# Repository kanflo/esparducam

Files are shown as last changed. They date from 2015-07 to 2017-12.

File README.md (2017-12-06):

# Esparducam
#### A low cost network camera for the ESP8266

This repository contains code and schematics to build a development board joining the ESP8266 with the [Arducam Mini](http://www.arducam.com/arducam-mini-released/) module. Build surveillance cameras, read your water meter, attach one to your kite.

<p align="center">
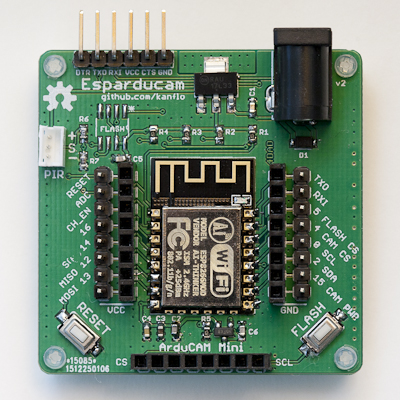
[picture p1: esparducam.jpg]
Esparducam board
  
</p>

The board design allows for small breakout boards to be attached. There currently is [a breakout board the the RFM69C](https://github.com/kanflo/esparducam/tree/master/hardware/ism-boardlet), [an ESP12 board with pogo pins](https://github.com/kanflo/esparducam/tree/master/hardware/esp-pinlet) and [one for swappable ESP12 modules](https://github.com/kanflo/esparducam/tree/master/hardware/esp-boardlet).

Oh, the accompanying blog posts are [here](http://johan.kanflo.com/building-a-low-cost-wifi-camera/), [here](http://johan.kanflo.com/a-versatile-esp8266-development-board/) and [here](http://johan.kanflo.com/esparducam-mini/).

### Usage

Clone the ESP Open RTOS repository. See the documentation for how to add your SSID name and password.

```
git clone --recursive https://github.com/Superhouse/esp-open-rtos.git
```

Add nedded extra modules to ESP Open RTOS ("EOR"):

```
cd esp-open-rtos/extras
git clone https://github.com/kanflo/eor-spi.git spi
git clone https://github.com/kanflo/eor-http-upload.git http-upload
```

Someday I'll start using the native EOR SPI driver, you have to bear with me for now :)

Set the environment variable ```$EOR_ROOT```to point to your EOR repository:

```
export EOR_ROOT=/path/to/esp-open-rtos
```

Clone this repository, make and flash:

```
git clone --recursive https://github.com/kanflo/esparducam.git
cd esparducam
make -j8 && make flash
```

The repository is preconfigured for the Esparducam board. Check ```config.h``` for building for the Esparducam Mini.

When flashing has completed, open a serial terminal to learn the IP number of your board. Open a web brower, point it to your IP and an image should be captured and displayed. While in the serial terminal, type ```help``` for a list of supported commands.

Start the python script ```server.py``` and type ```upload:<your IP>``` to capture, upload and display an image on your computer.

If you connect a [PIR module](http://www.ebay.com/sch/i.html?_trksid=PIR+module.TRS0&_nkw=PIR+module&_sacat=0) [eBay] to the JST connector of the Esparducam board you can use the command ```motion:on:<your ip>``` to have the board capture and upload an image when motion is detected. The Mini variant has a 3 pin slot for attaching a PIR but you need to check the pinout carefully. It should be VCC, OUT, GND but I have seen other combinations.

### Limitations

This is work in progress and there is currently very little error handling. Simultaneous clients will break the camera demo.

-

Licensed under the MIT license. Have fun!

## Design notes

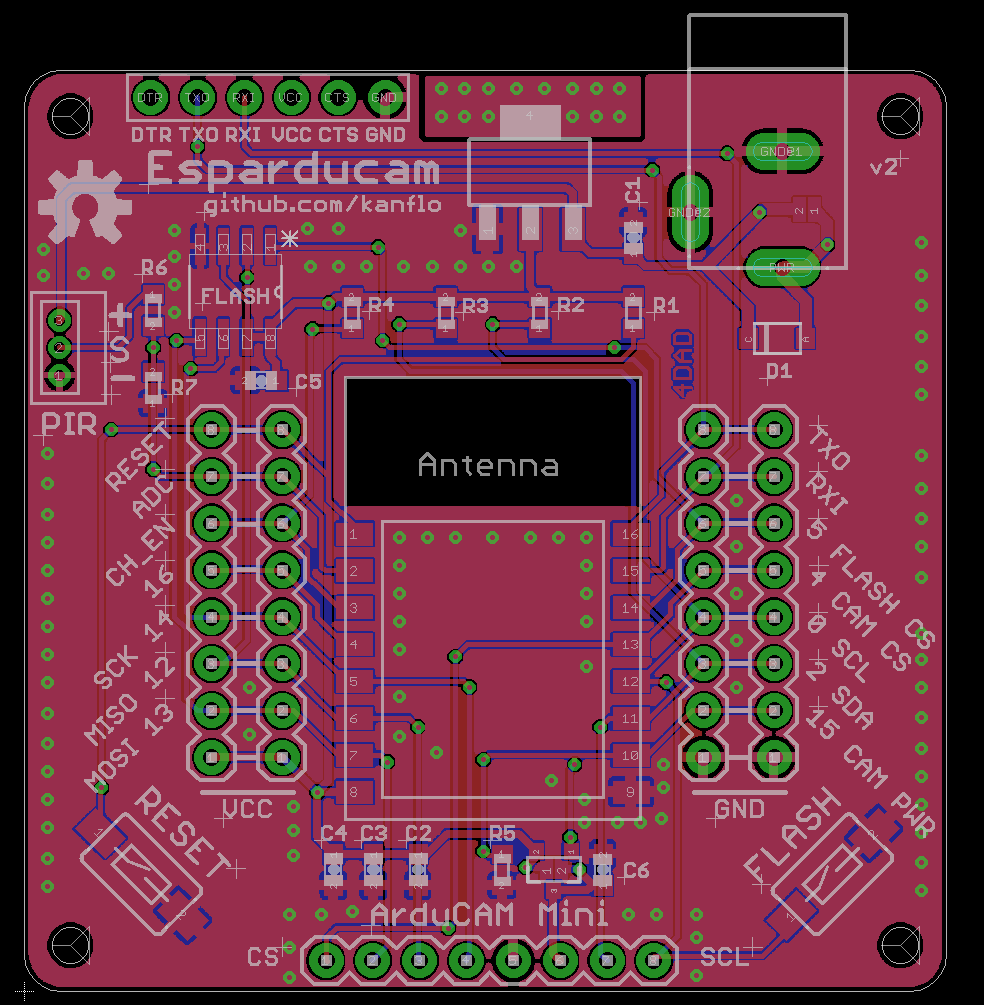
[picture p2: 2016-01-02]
hardware/esparducam-v2/esparducam-v2.png

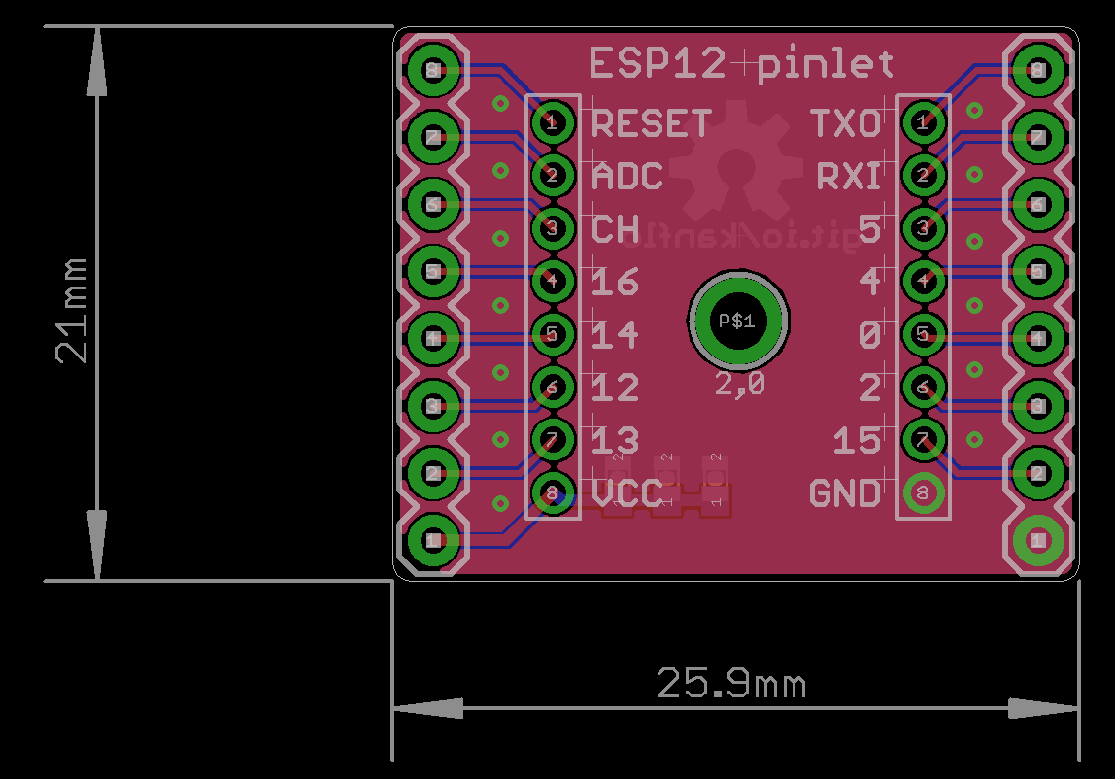
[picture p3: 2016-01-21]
hardware/esp-pinlet/esp-pinlet.png

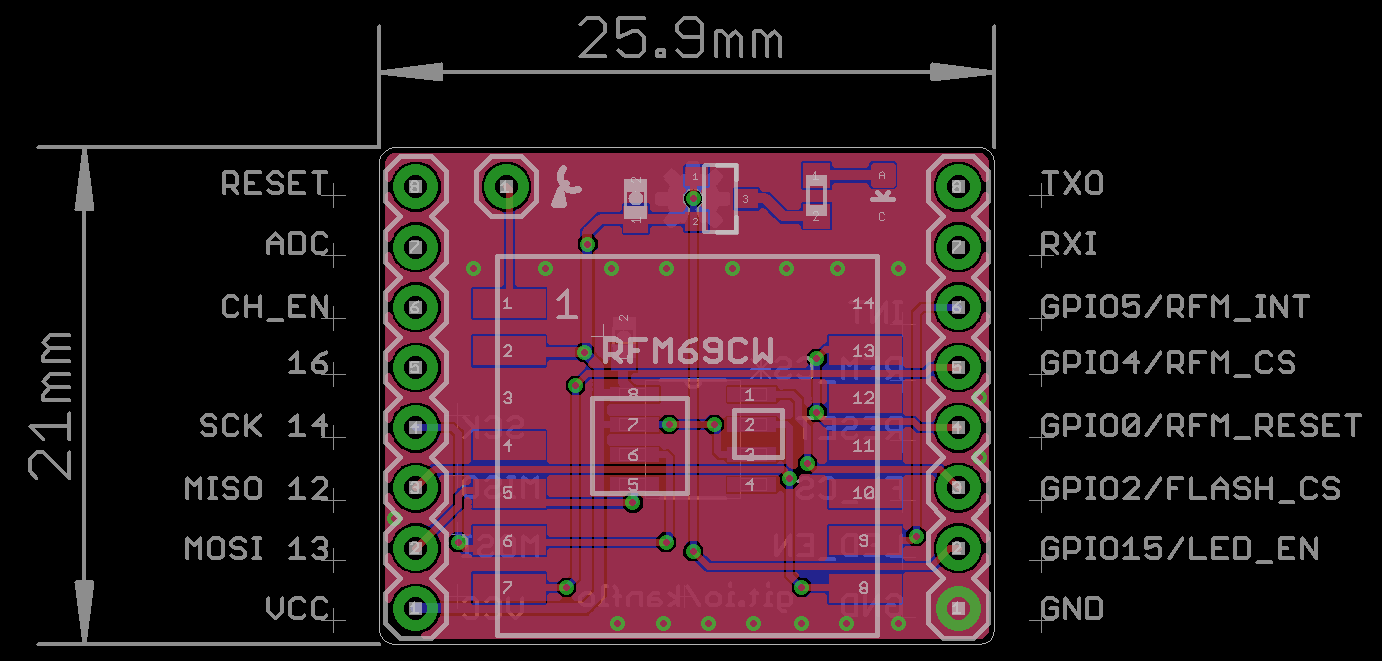
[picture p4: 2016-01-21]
hardware/ism-boardlet/ism-boardlet.png

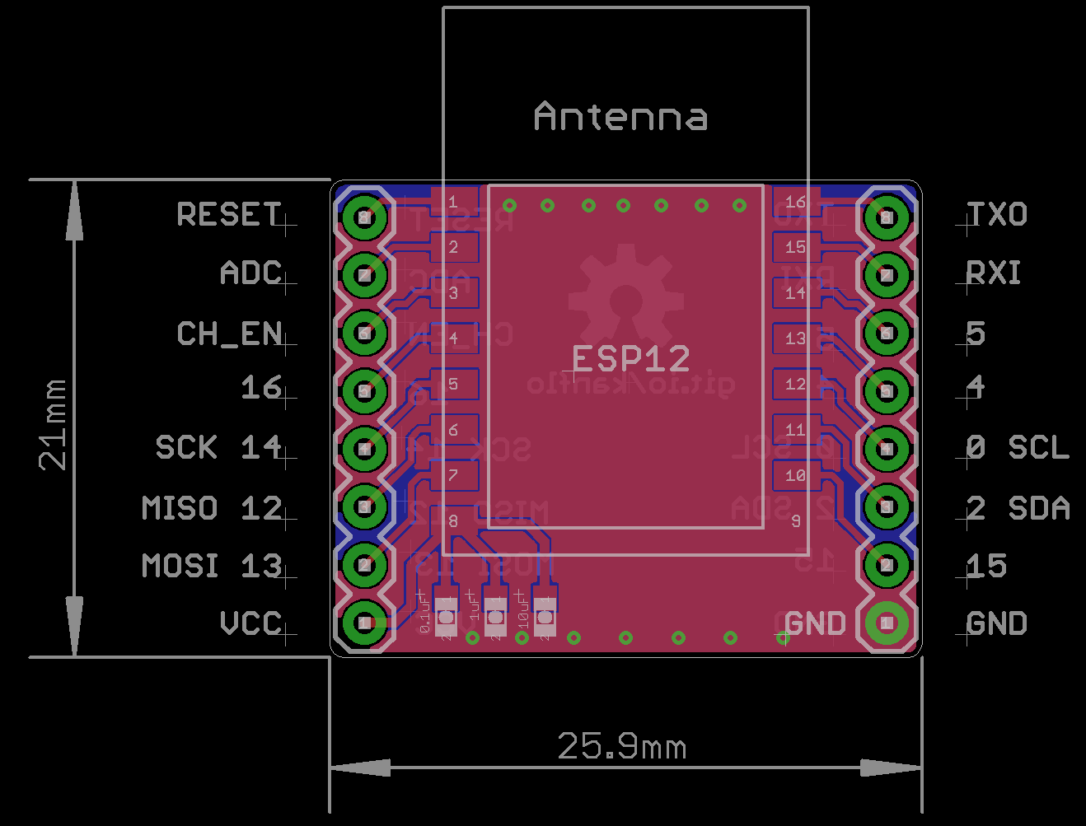
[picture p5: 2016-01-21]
hardware/esp-boardlet/esp-boardlet.png

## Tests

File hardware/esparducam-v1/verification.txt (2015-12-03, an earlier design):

Verification
------------
This document outlines the verification plan of the Esparducam v1 board.

No shorts found
 - checked VCC/GND
 - checked all ESP pins

Verification plan
 - Verify power - check
 - Barrel polarity - check
 - Regulator output (U1) - check
 - Verify mosfet power supply for ArduCAM module (Q1) - check
 - Produce a board with
    C1 C2
    R1 R2 R3 R4 R5 R6
    SPI flash
    Q1
    U1

Issues found
 - Footprint/silkscreen mismatch for the barrel connector.
 - Swapped RX/TX on the FTDI connector. Need to make a special cable, swap yellow and orange.
 - NCP1117 GND pin not directly routed to GND plane.
 - ArduCAM Mini has a pullup on its CS pin which is connected to GPIO15. The ESP will not boot with the ACAM module attached. Fix is to move CAM_CS to GPIO4.
 - One of the ESP modules had a broken Wifi antenna. Need a way to verify modules prior to mounting.
 - FTDI connector silk is ugly
 - Wrong footprint for Q1, selected SOT-323 instead of SOT-23. Luckily solder will make a '23 sit on the '323 pads :)

Planned changes for v2
 + Fix footprint of barrel connector.
 + Fix swapped UART RX/TX pins.
 + Fix FTDI connector silk.
 + Add label "Flash" under the SPI flash.
 + Replace BOOT label with FLASH.
 + Replace N-mosfet with a P-mosfet cutting power on the high side (check Harizanov's Funky with RFM12).
 + Move CAM_CS to GPIO 4.
 + Move CAM_PWR to GPIO 15.
 + NCP1117 GND pin not directly routed to GND plane.
 + Move SJ1 to the back side
 + Skip SJ2
 + Add protective diode with SJ bypass
 + Place 0.1uF, 1uF & 10uF close to ESP VCC
 + Add label for flash size under the board in the same manner as the "ESP type" label.
 + Change footprint for Q1 to SOT-23

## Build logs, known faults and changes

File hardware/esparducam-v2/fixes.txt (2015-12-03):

[X] Fix footprint of barrel connector.
[X] Fix swapped UART RX/TX pins.
[X] Move CAM_CS to GPIO 4.
[X] Move CAM_PWR to GPIO 15.
[X] Fix FTDI connector silk.
[X] Investigate a P-mosfet cutting power on the high side (check Harizanov's Funky with RFM12).
[X] NCP1117 GND pin not directly routed to GND plane.
[X] Skip SJ2.
[X] Investigate VCC filtering.
[X] Add label for flash size under the board in the same manner as the "ESP type" label.
[X] Add label "Flash" under the SPI flash.
[X] Replace BOOT label with FLASH.
[X] Check GPIO4 and GPIO5 (is the correct order TX, RX, GPIO5, GPIO4, ... ?)
[ ] Make the ESP12e pads 1mm wider
[X] Remove R6
[X] Check footprint of Q1 (seems to small)
[X] Add a schottky diode for reverse voltage protection and SJ bypass

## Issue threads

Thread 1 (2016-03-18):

Arduino friendly code

mkeyno, 2016-03-18:
hi @kanflo  and thanks for sharing the project , I'm arduino fan and I was wondering any plan to make your code in arduino  friendly environment such as arducam
BR

kanflo, 2016-03-18:
Thanks for taking interest @mkeyno. There already is a nice port for the Arduino environment at https://github.com/ArduCAM/Arduino (both AVR and ESP8266 based). I am afraid I will not find the time to make an Arduino version of my camera demo.

mkeyno, 2016-03-18:
thanks @kanflo for quick reply , yes I know those code and I was hopping to have your code in Arduino platform , thanks any way

Closed 2017-04-10.

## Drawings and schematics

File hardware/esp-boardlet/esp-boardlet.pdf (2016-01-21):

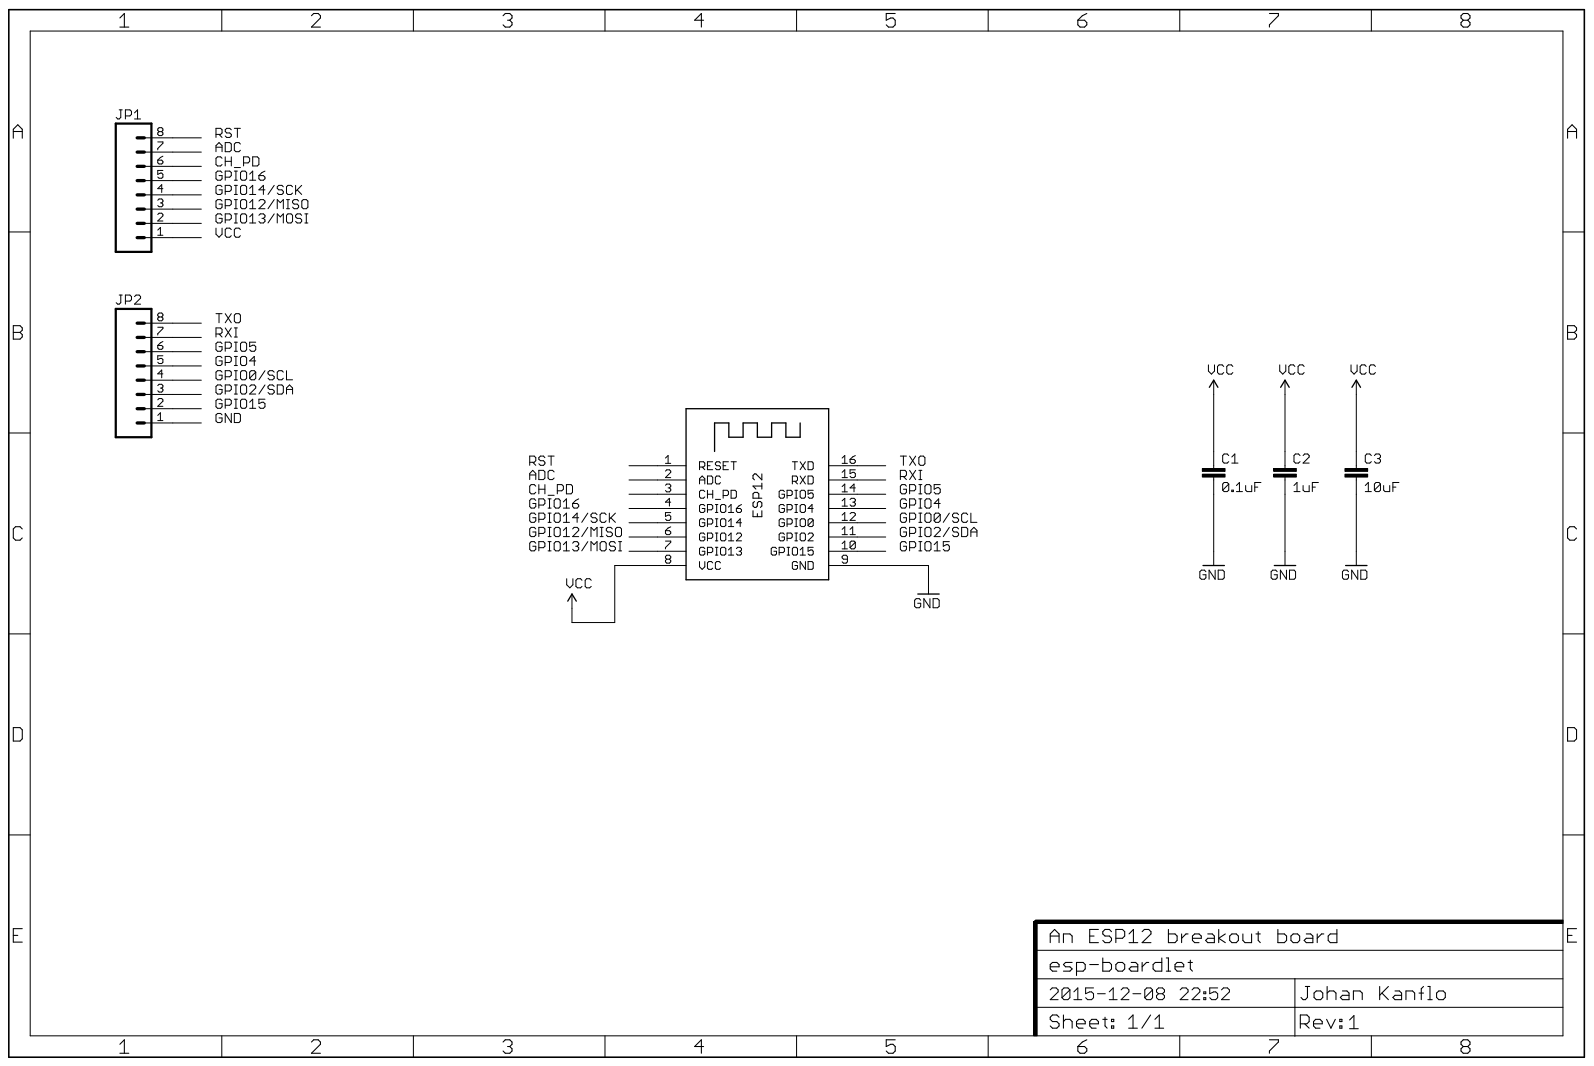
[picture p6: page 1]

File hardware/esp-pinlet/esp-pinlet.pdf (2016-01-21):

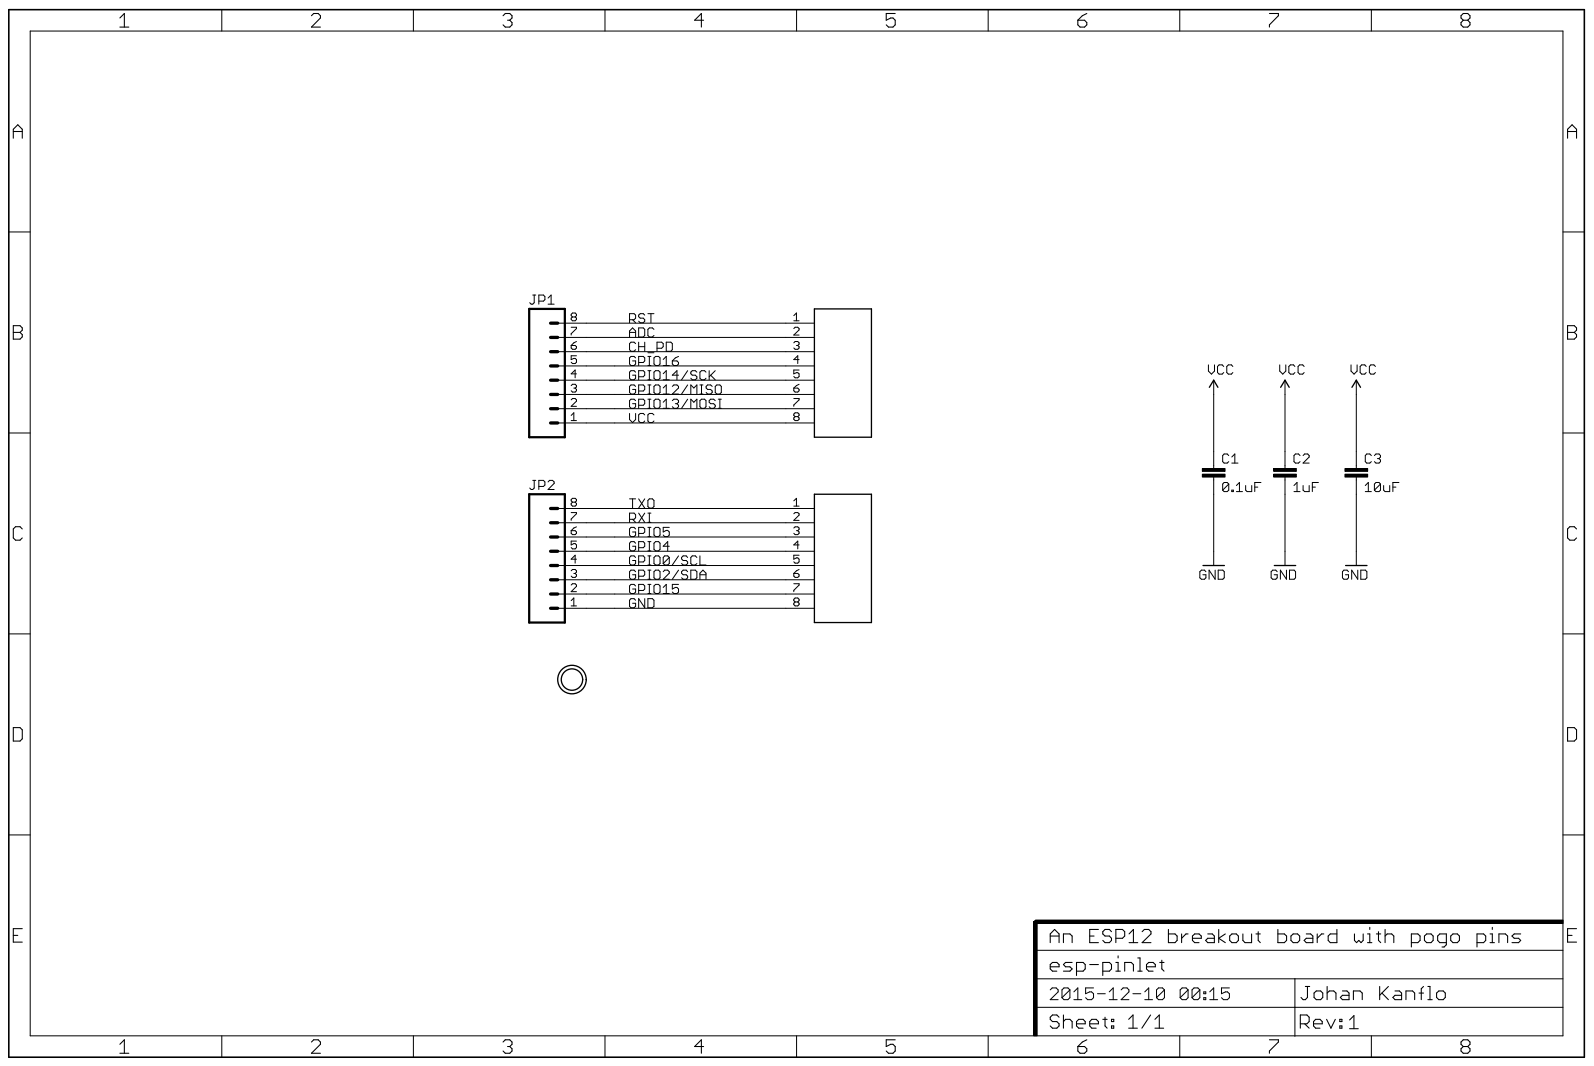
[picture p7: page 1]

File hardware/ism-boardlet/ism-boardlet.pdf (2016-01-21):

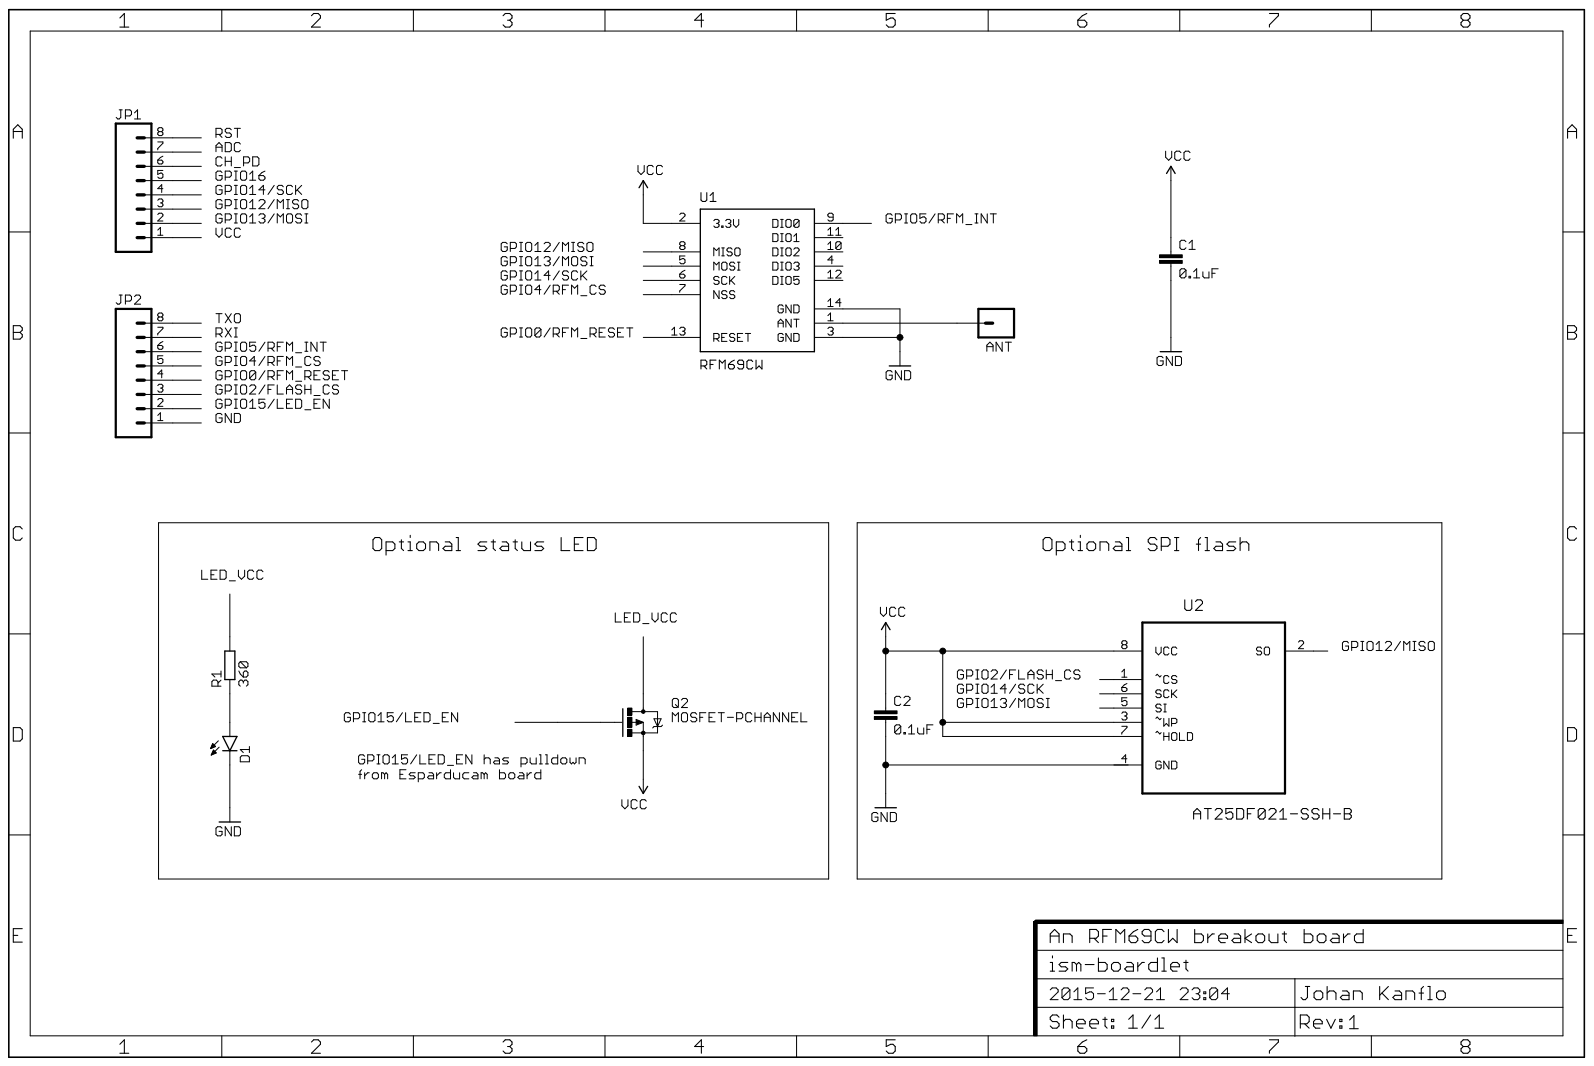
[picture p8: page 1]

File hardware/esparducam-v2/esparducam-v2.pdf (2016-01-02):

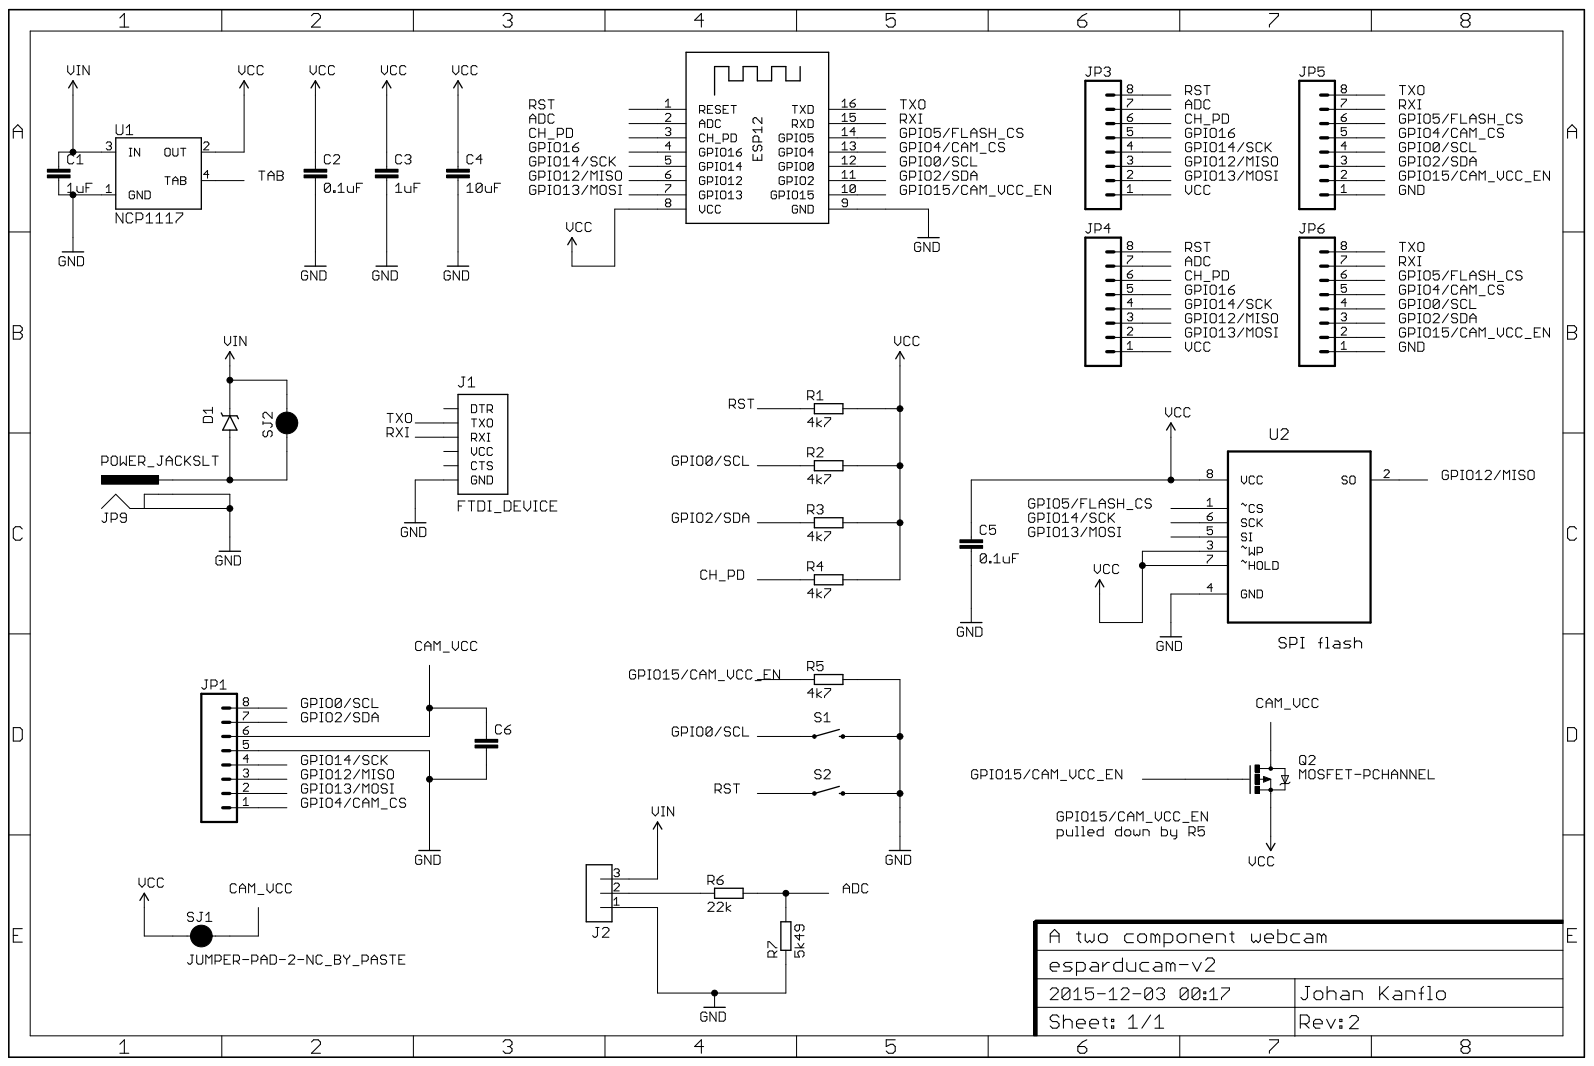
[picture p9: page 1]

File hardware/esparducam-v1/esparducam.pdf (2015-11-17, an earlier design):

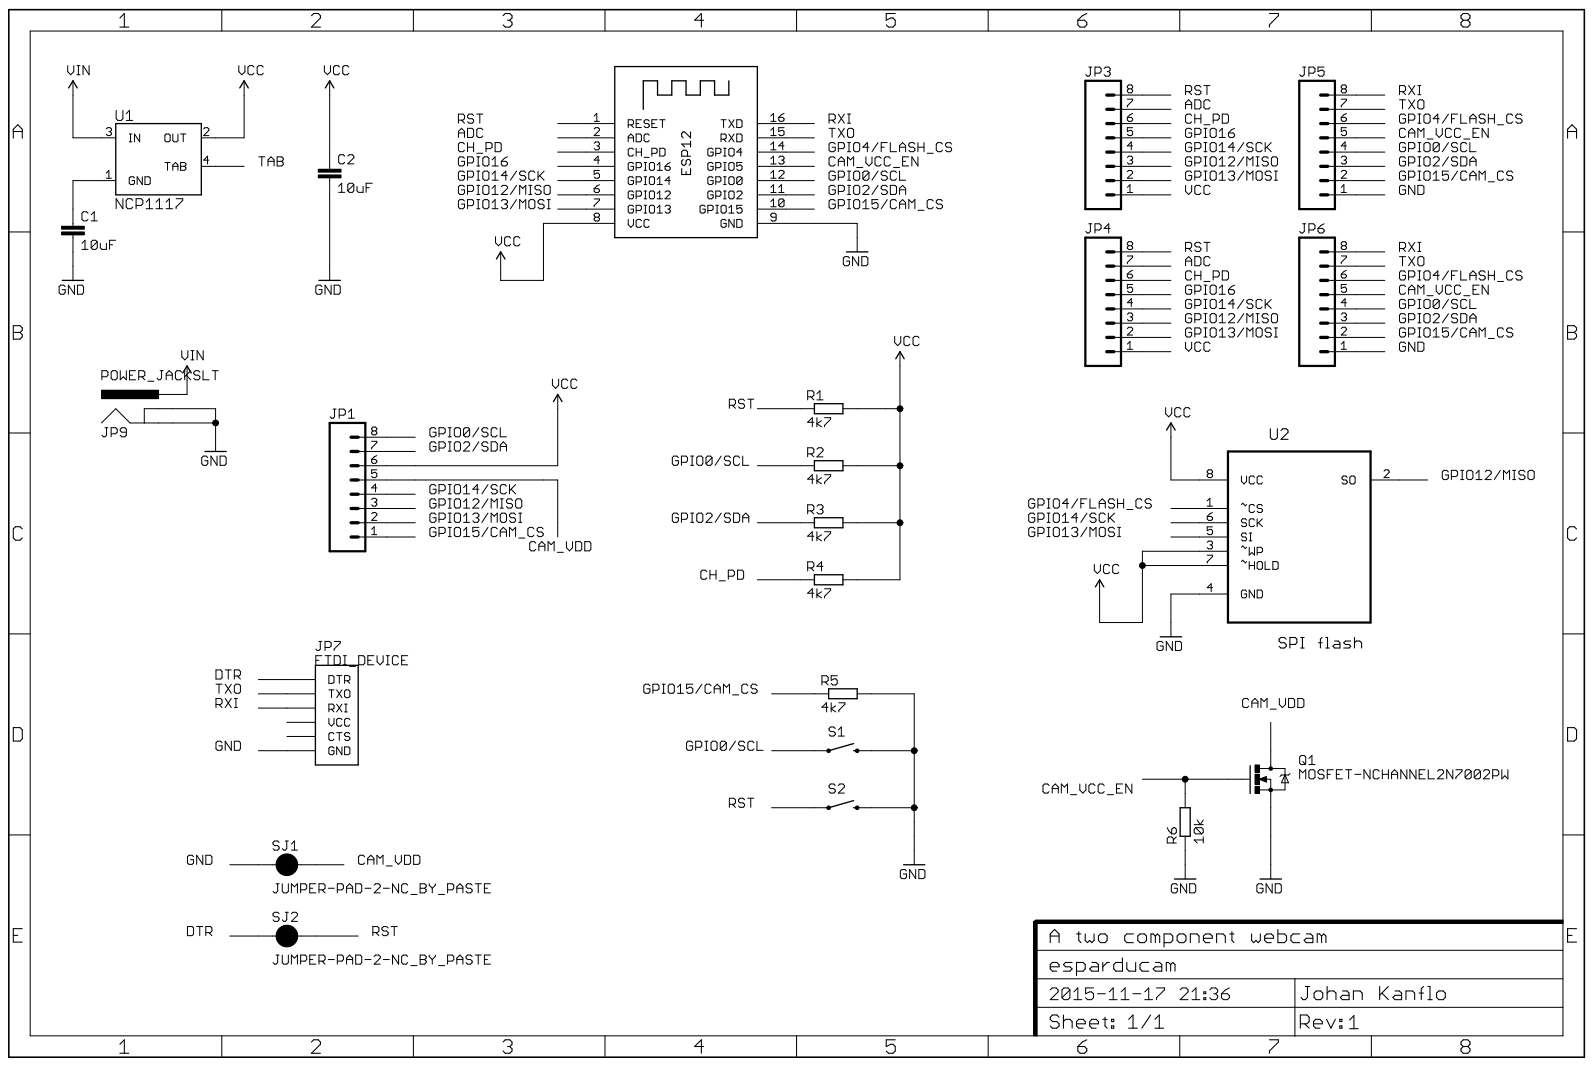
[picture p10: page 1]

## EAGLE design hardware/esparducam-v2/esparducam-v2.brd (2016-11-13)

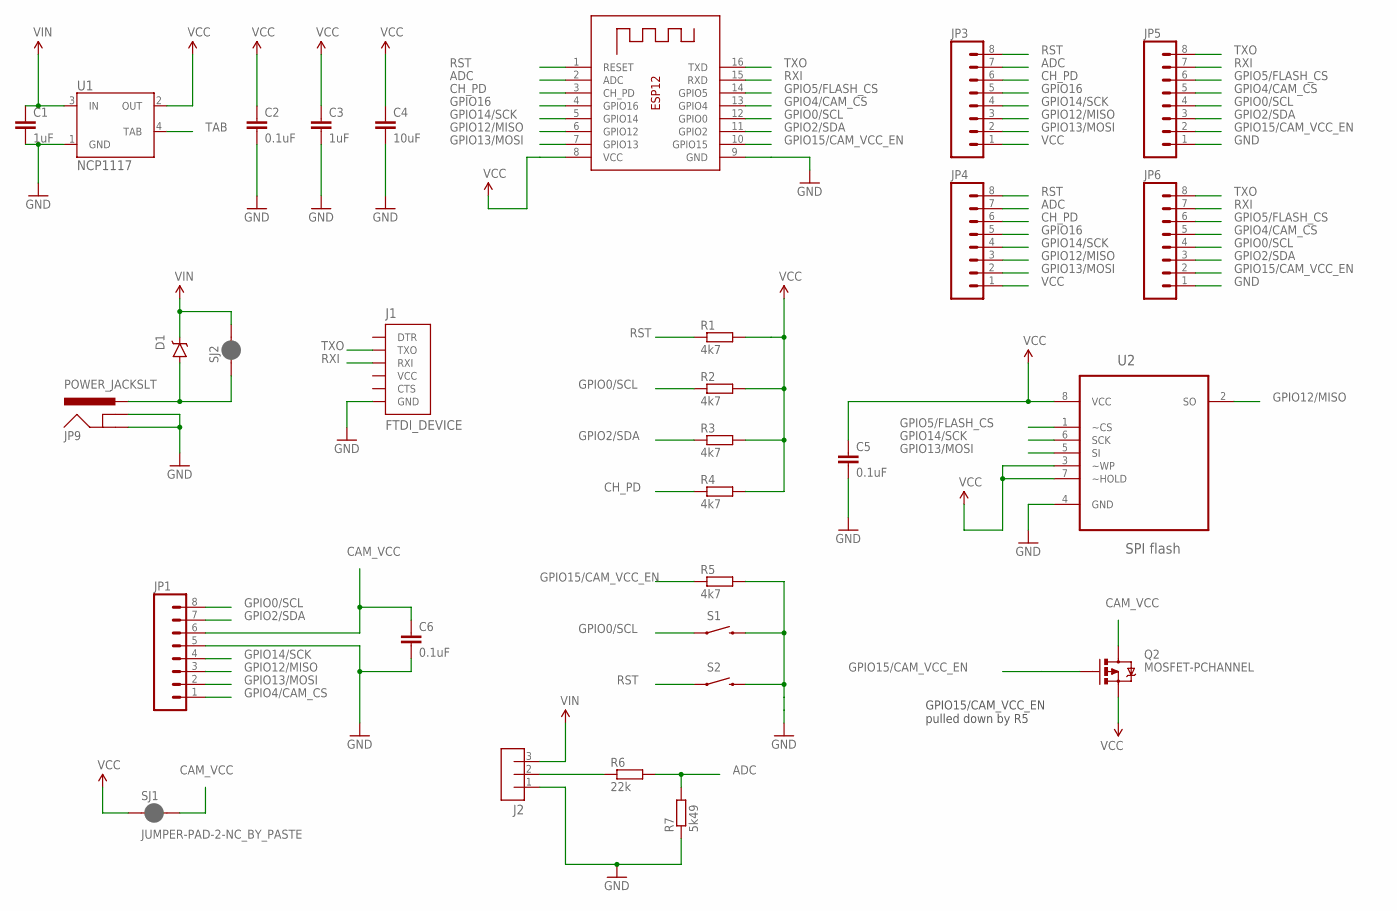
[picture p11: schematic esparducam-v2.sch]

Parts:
C1, C3: 1uF; 0603-CAP
C2, C5, C6: 0.1uF; 0603-CAP
C4: 10uF; 0603-CAP
D1: DIODE-SCHOTTKYSOD-123FL; SOD-123FL
J1: FTDI_DEVICE; FTDI
J2: JST_ZH_3PIN
JP1, JP3, JP4, JP5, JP6: M08; 1X08_ROUND
JP9: POWER_JACKSLT; POWER_JACK_SLOT
Q2: MOSFET-PCHANNEL; SOT23-3
R1, R2, R3, R4, R5: 4k7; R0603
R6: 22k; R0603
R7: 5k49; R0603
S1, S2: SWITCH-MOMENTARY-2SMD-1101NE; TACTILE-SWITCH-1101NE
SJ1, SJ2: JUMPER-PAD-2-NC_BY_PASTE; PAD-JUMPER-2-NC_BY_PASTE_YES_SILK
U1: NCP1117; SOT223
U2: SPI flash; SOIC127P600X175-8N
X1: ESP-12

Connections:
ADC: JP3.7, JP4.7, R6.2, R7.2, X1.2 (ADC)
CAM_VCC: C6.1, JP1.6, Q2.3 (D), SJ1.2
CH_PD: JP3.6, JP4.6, R4.1, X1.3 (CH_PD)
GND: C1.2, C2.2, C3.2, C4.2, C5.2, C6.2, J1.GND, J2.1, JP1.5, JP5.1, JP6.1, JP9.GND@1 (GNDBREAK), JP9.GND@2 (GND), R5.2, R7.1, S1.2, S2.2, U1.1 (GND), U2.4 (GND), X1.9 (GND)
GPIO0/SCL: JP1.8, JP5.4, JP6.4, R2.1, S1.1, X1.12 (GPIO0)
GPIO2/SDA: JP1.7, JP5.3, JP6.3, R3.1, X1.11 (GPIO2)
GPIO4/CAM_CS: JP1.1, JP5.5, JP6.5, X1.13 (GPIO4)
GPIO5/FLASH_CS: JP5.6, JP6.6, U2.1 (~CS), X1.14 (GPIO5)
GPIO12/MISO: JP1.3, JP3.3, JP4.3, U2.2 (SO), X1.6 (GPIO12)
GPIO13/MOSI: JP1.2, JP3.2, JP4.2, U2.5 (SI), X1.7 (GPIO13)
GPIO14/SCK: JP1.4, JP3.4, JP4.4, U2.6 (SCK), X1.5 (GPIO14)
GPIO15/CAM_VCC_EN: JP5.2, JP6.2, Q2.1 (G), R5.1, X1.10 (GPIO15)
GPIO16: JP3.5, JP4.5, X1.4 (GPIO16)
unnamed: J2.2, R6.1
unnamed: D1.A, JP9.PWR, SJ2.1
RST: JP3.8, JP4.8, R1.1, S2.1, X1.1 (RESET)
RXI: J1.RXI, JP5.7, JP6.7, X1.15 (RXD)
TAB: U1.4 (TAB)
TXO: J1.TXO, JP5.8, JP6.8, X1.16 (TXD)
VCC: C2.1, C3.1, C4.1, C5.1, JP3.1, JP4.1, Q2.2 (S), R1.2, R2.2, R3.2, R4.2, SJ1.1, U1.2 (OUT), U2.3 (~WP), U2.7 (~HOLD), U2.8 (VCC), X1.8 (VCC)
VIN: C1.1, D1.C, J2.3, SJ2.2, U1.3 (IN)

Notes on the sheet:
GPIO15/CAM_VCC_EN pulled down by R5

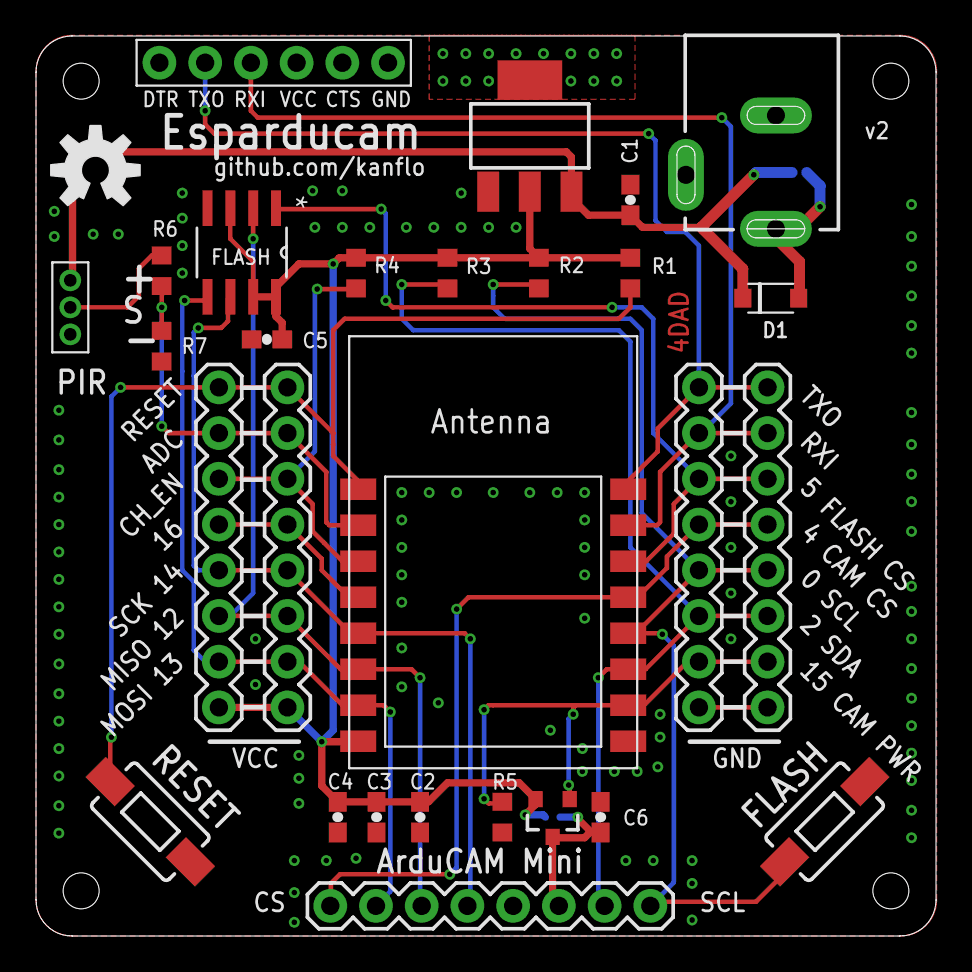
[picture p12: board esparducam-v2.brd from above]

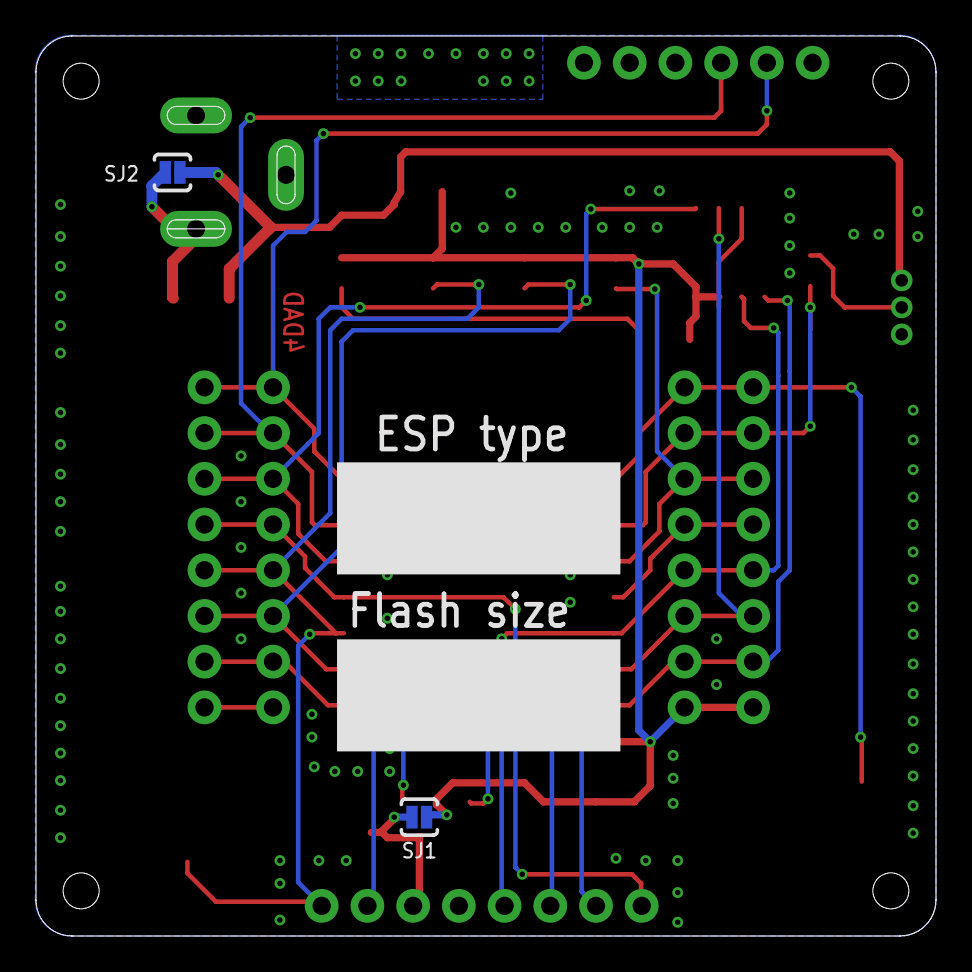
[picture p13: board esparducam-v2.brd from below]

Board: 2 copper layers, 50.0 x 50.0 mm, 31 parts (2 on the bottom side), 20 nets.

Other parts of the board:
U$1: OSHW-LOGO-M

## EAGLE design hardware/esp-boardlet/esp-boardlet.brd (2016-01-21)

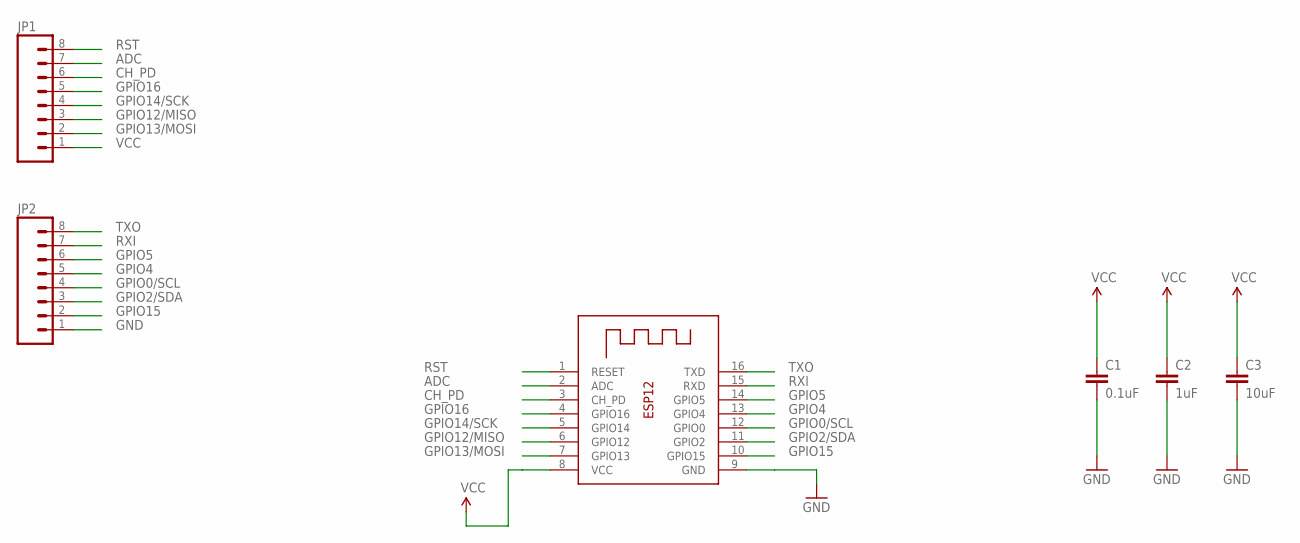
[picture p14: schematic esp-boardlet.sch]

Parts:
C1: 0.1uF; 0603-CAP
C2: 1uF; 0603-CAP
C3: 10uF; 0603-CAP
JP1, JP2: M08; 1X08_ROUND
X1: ESP-12

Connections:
ADC: JP1.7, X1.2 (ADC)
CH_PD: JP1.6, X1.3 (CH_PD)
GND: C1.2, C2.2, C3.2, JP2.1, X1.9 (GND)
GPIO0/SCL: JP2.4, X1.12 (GPIO0)
GPIO2/SDA: JP2.3, X1.11 (GPIO2)
GPIO4: JP2.5, X1.13 (GPIO4)
GPIO5: JP2.6, X1.14 (GPIO5)
GPIO12/MISO: JP1.3, X1.6 (GPIO12)
GPIO13/MOSI: JP1.2, X1.7 (GPIO13)
GPIO14/SCK: JP1.4, X1.5 (GPIO14)
GPIO15: JP2.2, X1.10 (GPIO15)
GPIO16: JP1.5, X1.4 (GPIO16)
RST: JP1.8, X1.1 (RESET)
RXI: JP2.7, X1.15 (RXD)
TXO: JP2.8, X1.16 (TXD)
VCC: C1.1, C2.1, C3.1, JP1.1, X1.8 (VCC)

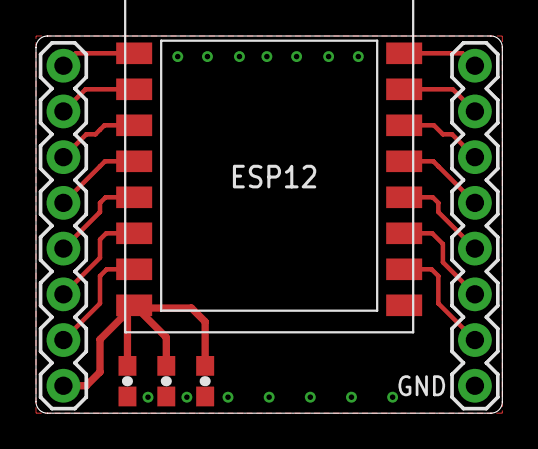
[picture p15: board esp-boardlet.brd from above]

Board: 2 copper layers, 25.9 x 21.0 mm, 7 parts (1 on the bottom side), 16 nets.

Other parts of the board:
U$1: OSHW-LOGO-M

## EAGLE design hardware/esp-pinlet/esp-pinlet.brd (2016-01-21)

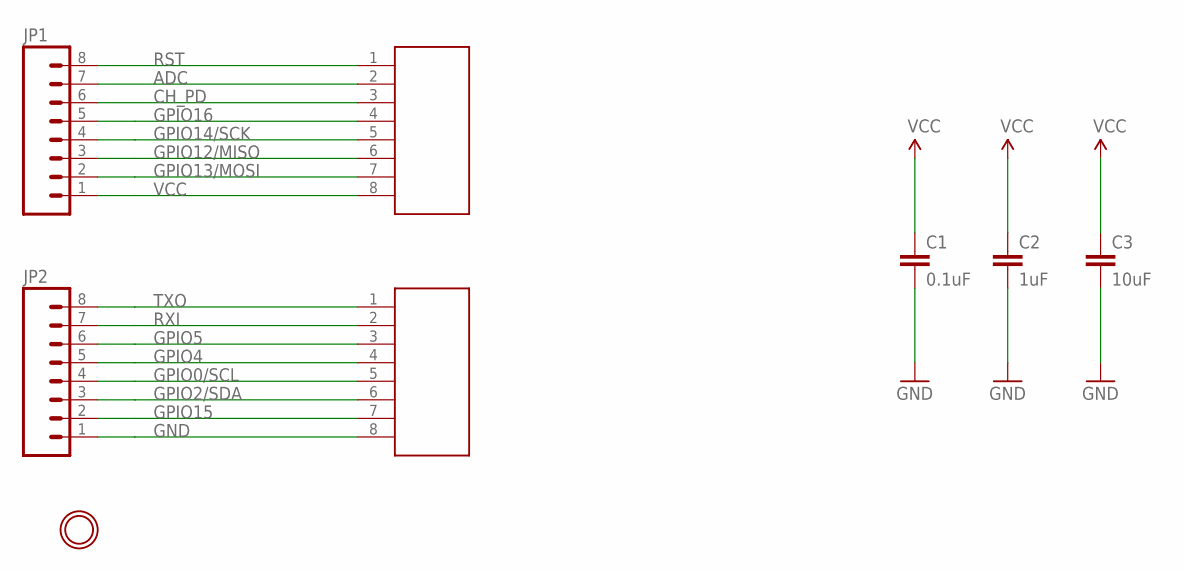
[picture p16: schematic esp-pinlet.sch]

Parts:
C1: 0.1uF; 0603-CAP
C2: 1uF; 0603-CAP
C3: 10uF; 0603-CAP
JP1, JP2: M08; 1X08_ROUND
U$2, U$3: 82XMM_POGO_PIN; 8X2MM_POGO_PIN
U$6: MOUNTINGHOLE2.0; MOUNTINGHOLE_2.0_PLATED

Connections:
ADC: JP1.7, U$2.2
CH_PD: JP1.6, U$2.3
GND: C1.2, C2.2, C3.2, JP2.1, U$3.8
GPIO0/SCL: JP2.4, U$3.5
GPIO2/SDA: JP2.3, U$3.6
GPIO4: JP2.5, U$3.4
GPIO5: JP2.6, U$3.3
GPIO12/MISO: JP1.3, U$2.6
GPIO13/MOSI: JP1.2, U$2.7
GPIO14/SCK: JP1.4, U$2.5
GPIO15: JP2.2, U$3.7
GPIO16: JP1.5, U$2.4
RST: JP1.8, U$2.1
RXI: JP2.7, U$3.2
TXO: JP2.8, U$3.1
VCC: C1.1, C2.1, C3.1, JP1.1, U$2.8

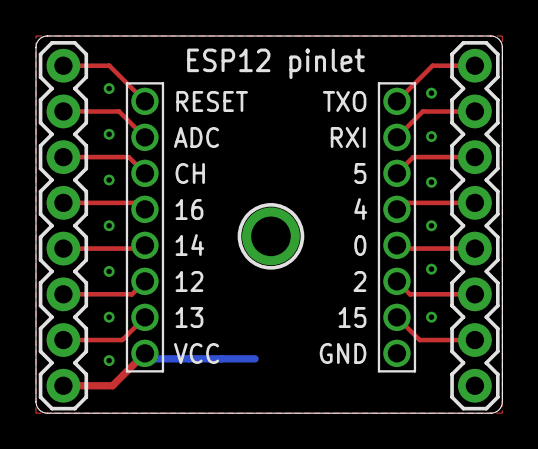
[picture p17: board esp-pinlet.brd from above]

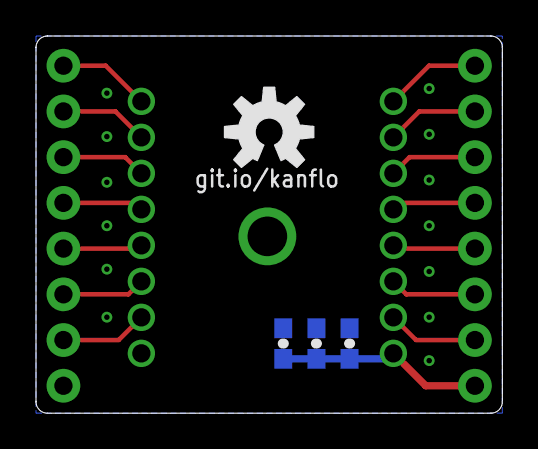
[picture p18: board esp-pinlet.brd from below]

Board: 2 copper layers, 25.9 x 21.0 mm, 9 parts (4 on the bottom side), 16 nets.

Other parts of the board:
U$1: OSHW-LOGO-M

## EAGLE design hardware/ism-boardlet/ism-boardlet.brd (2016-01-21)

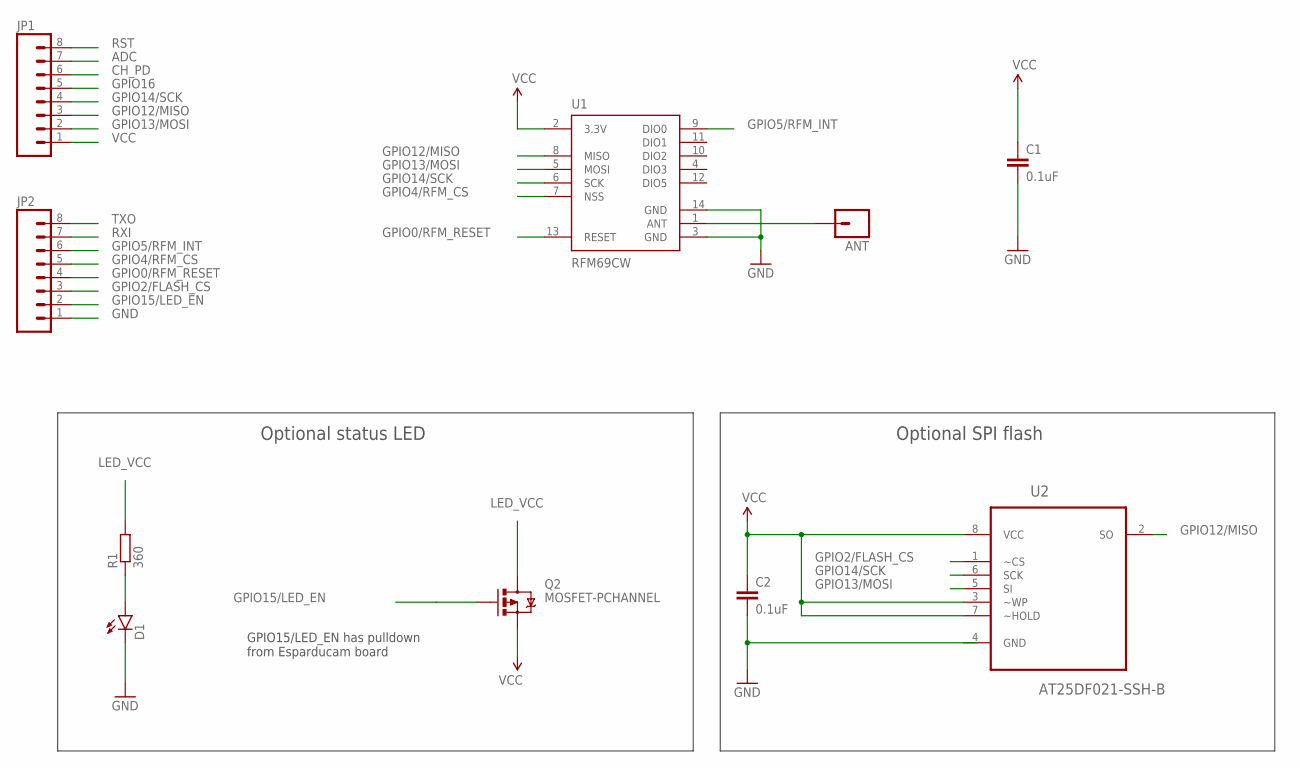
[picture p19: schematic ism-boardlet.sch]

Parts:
ANT: M01PTH; 1X01
C1, C2: 0.1uF; 0603-CAP
D1: LED0603; LED-0603
JP1, JP2: M08; 1X08_ROUND
Q2: MOSFET-PCHANNEL; SOT23-3
R1: 360; R0603
U1: RFM69CW; RFM69CW-XXXS2
U2: AT25DF021-SSH-B; SOIC127P600X175-8N

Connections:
ADC: JP1.7
CH_PD: JP1.6
GND: C1.2, C2.2, D1.C, JP2.1, U1.3 (GND), U1.14 (GND)
GPIO0/RFM_RESET: JP2.4, U1.13 (RESET)
GPIO2/FLASH_CS: JP2.3, U2.1 (~CS)
GPIO4/RFM_CS: JP2.5, U1.7 (NSS)
GPIO5/RFM_INT: JP2.6, U1.9 (DIO0)
GPIO12/MISO: JP1.3, U1.8 (MISO), U2.2 (SO)
GPIO13/MOSI: JP1.2, U1.5 (MOSI), U2.5 (SI)
GPIO14/SCK: JP1.4, U1.6 (SCK), U2.6 (SCK)
GPIO15/LED_EN: JP2.2, Q2.1 (G)
GPIO16: JP1.5
LED_VCC: Q2.3 (D), R1.2
unnamed: D1.A, R1.1
unnamed: ANT.1, U1.1 (ANT)
RST: JP1.8
RXI: JP2.7
TXO: JP2.8
VCC: C1.1, C2.1, JP1.1, Q2.2 (S), U1.2 (3.3V), U2.3 (~WP), U2.7 (~HOLD), U2.8 (VCC)

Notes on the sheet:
GPIO15/LED_EN has pulldown from Esparducam board
Optional status LED
Optional SPI flash

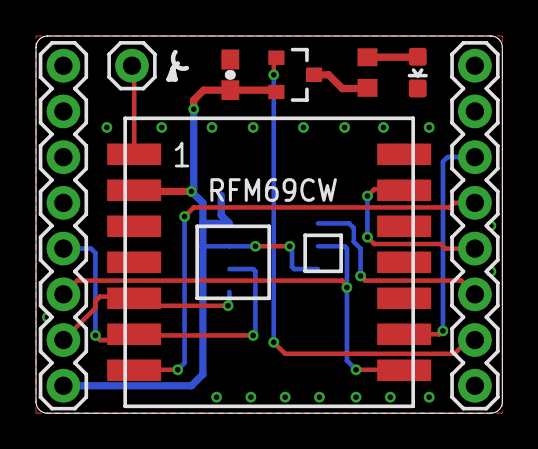
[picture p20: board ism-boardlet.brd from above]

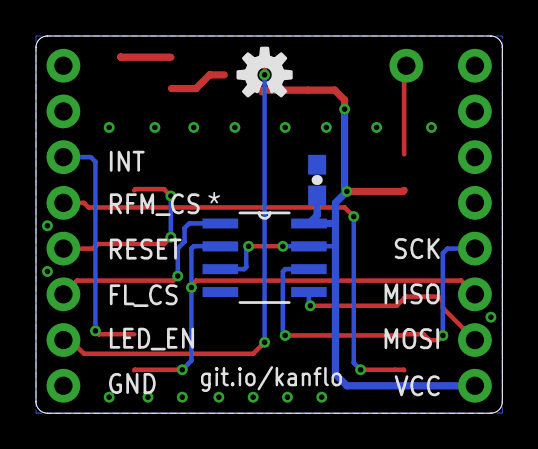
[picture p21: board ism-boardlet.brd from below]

Board: 2 copper layers, 25.9 x 21.0 mm, 11 parts (3 on the bottom side), 13 nets.

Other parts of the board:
U$2: OSHW-LOGO-S

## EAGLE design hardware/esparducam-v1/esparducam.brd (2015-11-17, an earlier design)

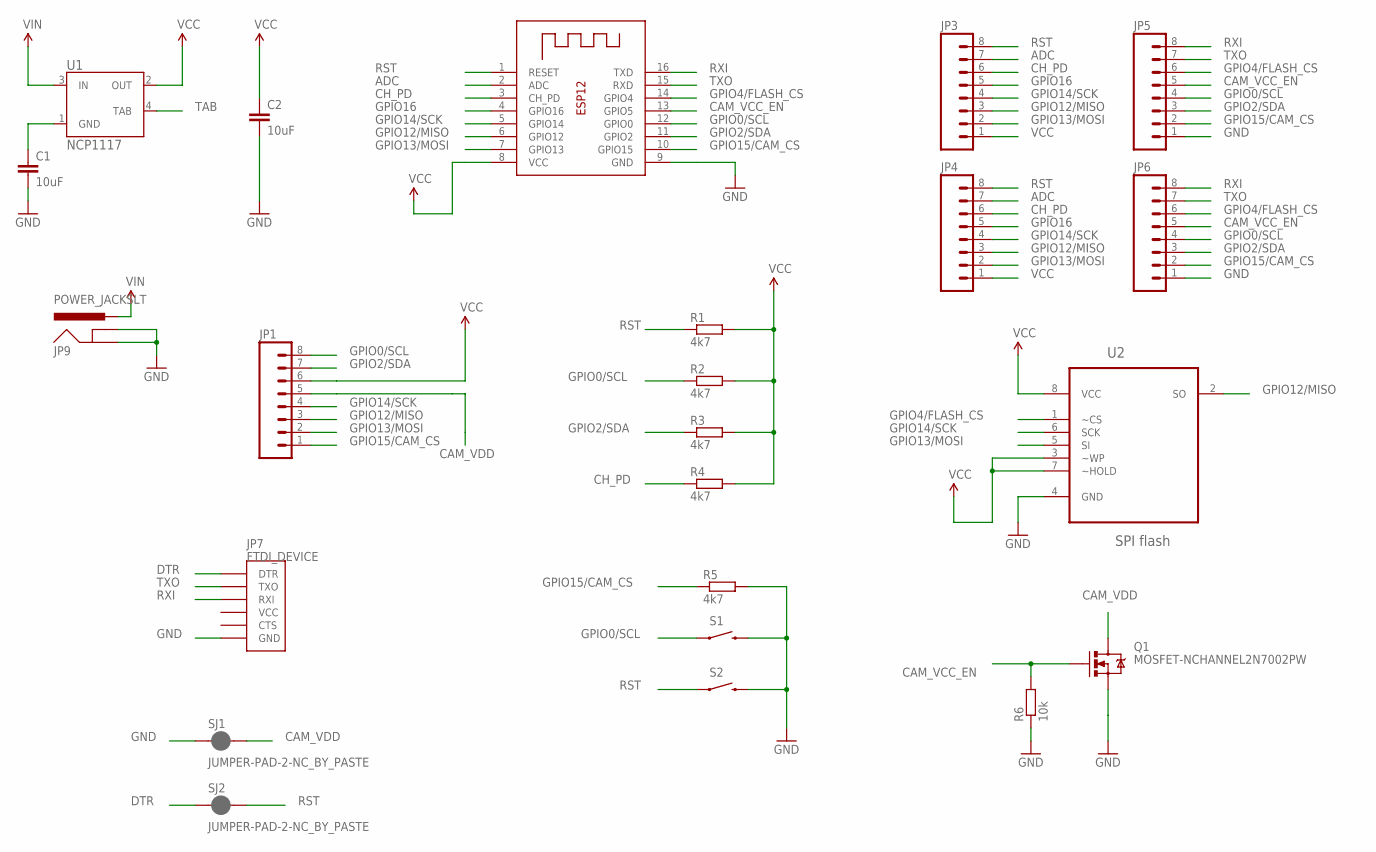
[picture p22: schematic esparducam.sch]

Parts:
C1, C2: 10uF; 0603-CAP
JP1, JP3, JP4, JP5, JP6: M08; 1X08_ROUND
JP7: FTDI_DEVICE; FTDI_DEVICE_SIDE
JP9: POWER_JACKSLT; POWER_JACK_SLOT
Q1: MOSFET-NCHANNEL2N7002PW; SOT323
R1, R2, R3, R4, R5: 4k7; R0603
R6: 10k; R0603
S1, S2: SWITCH-MOMENTARY-2SMD-1101NE; TACTILE-SWITCH-1101NE
SJ1, SJ2: JUMPER-PAD-2-NC_BY_PASTE; PAD-JUMPER-2-NC_BY_PASTE_YES_SILK
U1: NCP1117; SOT223
U2: SPI flash; SOIC127P600X175-8N
X1: ESP-12

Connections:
ADC: JP3.7, JP4.7, X1.2 (ADC)
CAM_VCC_EN: JP5.5, JP6.5, Q1.1 (G), R6.2, X1.13 (GPIO5)
CAM_VDD: JP1.5, Q1.3 (D), SJ1.2
CH_PD: JP3.6, JP4.6, R4.1, X1.3 (CH_PD)
DTR: JP7.P$1 (DTR), SJ2.1
GND: C1.2, C2.2, JP5.1, JP6.1, JP7.P$6 (GND), JP9.GND@1 (GNDBREAK), JP9.GND@2 (GND), Q1.2 (S), R5.2, R6.1, S1.2, S2.2, SJ1.1, U2.4 (GND), X1.9 (GND)
GPIO0/SCL: JP1.8, JP5.4, JP6.4, R2.1, S1.1, X1.12 (GPIO0)
GPIO2/SDA: JP1.7, JP5.3, JP6.3, R3.1, X1.11 (GPIO2)
GPIO4/FLASH_CS: JP5.6, JP6.6, U2.1 (~CS), X1.14 (GPIO4)
GPIO12/MISO: JP1.3, JP3.3, JP4.3, U2.2 (SO), X1.6 (GPIO12)
GPIO13/MOSI: JP1.2, JP3.2, JP4.2, U2.5 (SI), X1.7 (GPIO13)
GPIO14/SCK: JP1.4, JP3.4, JP4.4, U2.6 (SCK), X1.5 (GPIO14)
GPIO15/CAM_CS: JP1.1, JP5.2, JP6.2, R5.1, X1.10 (GPIO15)
GPIO16: JP3.5, JP4.5, X1.4 (GPIO16)
unnamed: C1.1, U1.1 (GND)
RST: JP3.8, JP4.8, R1.1, S2.1, SJ2.2, X1.1 (RESET)
RXI: JP5.8, JP6.8, JP7.P$3 (RXI), X1.16 (TXD)
TAB: U1.4 (TAB)
TXO: JP5.7, JP6.7, JP7.P$2 (TXO), X1.15 (RXD)
VCC: C2.1, JP1.6, JP3.1, JP4.1, R1.2, R2.2, R3.2, R4.2, U1.2 (OUT), U2.3 (~WP), U2.7 (~HOLD), U2.8 (VCC), X1.8 (VCC)
VIN: JP9.PWR, U1.3 (IN)


Board: 2 copper layers, 50.0 x 50.0 mm, 24 parts (0 on the bottom side), 20 nets.

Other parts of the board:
U$1: OSHW-LOGO-M

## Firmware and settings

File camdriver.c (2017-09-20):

/* 
 * The MIT License (MIT)
 * 
 * Copyright (c) 2016 Johan Kanflo (github.com/kanflo)
 * 
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
 * THE SOFTWARE IS PROVIDED "AS IS", WITHOUT WARRANTY OF ANY KIND, EXPRESS OR
 * IMPLIED, INCLUDING BUT NOT LIMITED TO THE WARRANTIES OF MERCHANTABILITY,
 * FITNESS FOR A PARTICULAR PURPOSE AND NONINFRINGEMENT. IN NO EVENT SHALL THE
 * AUTHORS OR COPYRIGHT HOLDERS BE LIABLE FOR ANY CLAIM, DAMAGES OR OTHER
 * LIABILITY, WHETHER IN AN ACTION OF CONTRACT, TORT OR OTHERWISE, ARISING FROM,
 * OUT OF OR IN CONNECTION WITH THE SOFTWARE OR THE USE OR OTHER DEALINGS IN
 * THE SOFTWARE.
 */

#include <arducam.h>
#include <unistd.h>
#include <string.h>
#include <http_upload.h>
#include "timeutils.h"
#include "camdriver.h"


#define MIN(a,b) (((a)<(b))?(a):(b))
#define MAX(a,b) (((a)>(b))?(a):(b))

#define BUF_SIZE (200)
static char buffer[BUF_SIZE];

bool arducam_setup(void)
{
    uint8_t vid, pid, temp;

    arducam(smOV2640);
    // Check if the ArduCAM SPI bus is OK
    arducam_write_reg(ARDUCHIP_TEST1, 0x55);
    temp = arducam_read_reg(ARDUCHIP_TEST1);
    if(temp != 0x55) {
        printf("SPI interface error (got 0x%02x)!\n", temp);
        return false;
    }

    // Change MCU mode
//    arducam_write_reg(ARDUCHIP_MODE, 0x00);

    // Check if the camera module type is OV2640
    arducam_i2c_read(OV2640_CHIPID_HIGH, &vid);
    arducam_i2c_read(OV2640_CHIPID_LOW, &pid);
    if((vid != 0x26) || (pid != 0x42)) {
        printf("Error: cannot find OV2640 module (got 0x%02x, 0x%02x)\n", vid, pid);
        return false;
    } else {
        printf("OV2640 detected\n");
    }
    printf("Setting JPEG\n");
    arducam_set_format(fmtJPEG);
    printf("Init\n");
    arducam_init(); // Note to self. Must call set_format before init.
    printf("Setting size\n");
    arducam_set_jpeg_size(sz640x480);
    // Allow for auto exposure loop to adapt to after resolution change
    printf("Autoexposure working...\n");
    delay_ms(1000);
    printf("Done...\n");
    return true;
}

bool arducam_capture(void)
{
    uint8_t temp;
    uint32_t start_time = systime_ms();

//    arducam_flush_fifo(); // TODO: These are the same
    arducam_clear_fifo_flag(); // TODO: These are the same
    printf("Start capture\n");
    arducam_start_capture();
    temp = arducam_read_reg(ARDUCHIP_TRIG);
    if (!temp) {
        printf("Failed to start capture!\n");
        return false;
    } else {
        while (!(arducam_read_reg(ARDUCHIP_TRIG) & CAP_DONE_MASK)) {
            delay_ms(1);
        }
        printf("Capture done after %ums\n", systime_ms()-start_time);
    }
    return true;
}

void arudcam_fifo_to_netcon(struct netconn *client)
{
    uint8_t temp, temp_last = 0, buf_idx = 0;
    uint32_t fifo_size, bytes_read, start_time = systime_ms();

    fifo_size = (arducam_read_reg(0x44) << 16) | (arducam_read_reg(0x43) << 8) | (arducam_read_reg(0x42));
    printf("%u bytes in fifo, according to camera\n", fifo_size); 

    bytes_read = 1;
    temp = arducam_read_fifo();
//    printf("%02x ", temp);
    buffer[buf_idx++] = temp;
    // Read JPEG data from FIFO
    while((temp != 0xd9) | (temp_last != 0xff)) {
        temp_last = temp;
        temp = arducam_read_fifo();
        buffer[buf_idx++] = temp;
        if (client && buf_idx == BUF_SIZE) {
            if (ERR_OK != netconn_write(client, buffer, buf_idx, NETCONN_COPY)) {
                printf("netconn_write failed\n");
                return;
            }
            buf_idx = 0;
        }
        bytes_read++;
        if (bytes_read > fifo_size) {
            printf("Fifo error\n");
            break;
        }
    }
    if (client && buf_idx > 0) {
        if (ERR_OK != netconn_write(client, buffer, buf_idx, NETCONN_COPY)) {
            printf("netconn_write failed\n");
        }
    }
    printf("Done, read %u bytes in %ums\n", bytes_read, systime_ms()-start_time);
}

void arudcam_fifo_to_devnull()
{
    uint8_t temp, temp_last = 0, buf_idx = 0;
    uint32_t fifo_size, bytes_read, start_time = systime_ms();

    fifo_size = (arducam_read_reg(0x44) << 16) | (arducam_read_reg(0x43) << 8) | (arducam_read_reg(0x42));
    printf("%u bytes in fifo, according to camera\n", fifo_size); 

    bytes_read = 1;
    temp = arducam_read_fifo();
//    printf("%02x ", temp);
    buffer[buf_idx++] = temp;
    // Read JPEG data from FIFO
    while((temp != 0xd9) | (temp_last != 0xff)) {
        temp_last = temp;
        temp = arducam_read_fifo();
        bytes_read++;
        if (bytes_read > fifo_size) {
            printf("Fifo error\n");
            break;
        }
    }
    printf("Done, read %u bytes in %ums\n", bytes_read, systime_ms()-start_time);
}

void arudcam_upload_fifo(char *host, uint16_t port)
{
    uint8_t temp, temp_last = 0, buf_idx = 0;
    uint32_t http_res, fifo_size, bytes_read, start_time = systime_ms();

    fifo_size = (arducam_read_reg(0x44) << 16) | (arducam_read_reg(0x43) << 8) | (arducam_read_reg(0x42));
    printf("%u bytes in fifo, according to camera\n", fifo_size); 

    do {
        printf("Connecting to server...\n");
        if (!upload_connect(host, port)) {
            printf("Failed to connect to %s:%d\n", host, port);
            break;
        }

        printf(" Connected\n");
        if (!upload_begin("/", "image.jpg", fifo_size)) {
            printf("Failed to upload\n");
            break;
        }
        printf("Uploading...\n");

        bytes_read = 1;
        temp = arducam_read_fifo();
        buffer[buf_idx++] = temp;
        // Read JPEG data from FIFO
        while((temp != 0xd9) | (temp_last != 0xff)) {
            temp_last = temp;
            temp = arducam_read_fifo();
            buffer[buf_idx++] = temp;
            if (buf_idx == BUF_SIZE) {
                if (!upload_data(buffer, buf_idx)) {
                    printf("Data upload failed\n");
                    break;
                }
                buf_idx = 0;
            }
            bytes_read++;
            if (bytes_read > fifo_size) {
                printf("Fifo error\n");
                break;
            }
        }
        if (buf_idx > 0) {
            (void) upload_data(buffer, buf_idx);
        }
        if (bytes_read < fifo_size) {
            printf("Padding upload data with %d bytes\n", fifo_size - bytes_read);
            memset(buffer, 0, BUF_SIZE);
            while (bytes_read < fifo_size) {
                uint32_t diff = fifo_size - bytes_read;
                (void) upload_data(buffer, MIN(diff, BUF_SIZE));
                bytes_read += MIN(diff, BUF_SIZE);
            }
        }
        printf("Finishing upload\n");
        http_res = upload_finish();
        printf("Closing\n");
        upload_close();
        printf("Done, read %u bytes in %ums, server responded with %d\n", bytes_read, systime_ms()-start_time, http_res);
    } while(0);
}

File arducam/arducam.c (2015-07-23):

/*
 * arducam.c
 *
 *  Created on: 2015.01.16
 *      Author: Lee
 */


/*
  ArduCAM.cpp - Arduino library support for CMOS Image Sensor
  Copyright (C)2011-2013 ArduCAM.com. All right reserved

  Basic functionality of this library are based on the demo-code provided by
  ArduCAM.com. You can find the latest version of the library at
  http://www.ArduCAM.com

  Now supported controllers:
		-	OV7670
		-	MT9D111
		-	OV7675
		-	OV2640
		-	OV3640
		-	OV5642
		-	OV7660
		-	OV7725

	We will add support for many other sensors in next release.

  Supported MCU platform
 		-	Theoretically support all Arduino families
  		-	Arduino UNO R3			(Tested)
  		-	Arduino MEGA2560 R3		(Tested)
  		-	Arduino Leonardo R3		(Tested)
  		-	Arduino Nano			(Tested)
  		-	Arduino DUE				(Tested)
  		-	Arduino Yun				(Tested)
  		-	Raspberry Pi			(Tested)

  If you make any modifications or improvements to the code, I would appreciate
  that you share the code with me so that I might include it in the next release.
  I can be contacted through http://www.ArduCAM.com

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
  You should have received a copy of the GNU Lesser General Public
  License along with this library; if not, write to the Free Software
  Foundation, Inc., 51 Franklin St, Fifth Floor, Boston, MA  02110-1301  USA
*/

/*------------------------------------
	Revision History:
	2015/01/16 	V1.0	by Lee	first release for Raspberry Pi
--------------------------------------*/

#include "arducam.h"
#include "arducam_arch.h"
#include "memorysaver.h"
#include <string.h>
#include <stdint.h>
#include <stdlib.h>
#include <time.h>

static struct CAM myCAM;

int arducam(sensor_model_t model)
{
	myCAM.sensor_model = model;
	switch(myCAM.sensor_model)
	{
		case smOV7660:
		case smOV7670:
		case smOV7675:
		case smOV7725:
			myCAM.sensor_addr = 0x21;
			break;
		case smMT9D111:
			myCAM.sensor_addr = 0x5d;
			break;
		case smOV3640:
		case smOV5642:
			myCAM.sensor_addr = 0x3c;
			break;
		case smOV2640:
		case smOV9655:
			myCAM.sensor_addr = 0x30;
			break;
		case smMT9M112:
			myCAM.sensor_addr = 0x5d;
			break;
		default:
			myCAM.sensor_addr = 0x21;
			break;
	}
	if (!arducam_spi_init()) {
		printf("ERROR: SPI init failed\n");
		return 0;
	}

	// initialize i2c:
	if (!arducam_i2c_init(myCAM.sensor_addr)) {
		printf("ERROR: I2C init failed\n");
		return 0;
	}
	return 1;
}

void arducam_init()
{
	switch(myCAM.sensor_model) {
#ifdef OV7660_CAM
		case smOV7660:
		{
			arducam_i2c_write(0x12, 0x80);
			arducam_delay_ms(100);
			(void) arducam_i2c_write_regs(OV7660_QVGA);
			break;
		}
#endif

#ifdef OV7725_CAM
		case smOV7725:
		{
			uint8_t reg_val;
			arducam_i2c_write(0x12, 0x80);
			arducam_delay_ms(100);
			(void) arducam_i2c_write_regs(OV7725_QVGA);
			arducam_i2c_read(0x15,&reg_val);
			arducam_i2c_write(0x15, (reg_val | 0x02));
			break;
		}
#endif

#ifdef OV7670_CAM
		case smOV7670:
		{
			arducam_i2c_write(0x12, 0x80);
			arducam_delay_ms(100);
			(void) arducam_i2c_write_regs(OV7670_QVGA);
			break;
		}
#endif

#ifdef OV7675_CAM
		case smOV7675:
		{
			arducam_i2c_write(0x12, 0x80);
			arducam_delay_ms(100);
			(void) arducam_i2c_write_regs(OV7675_QVGA);
			break;
		}
#endif

#ifdef MT9D111_CAM
		case smMT9D111:
		{
			//arducam_i2c_write_regs16(MT9D111_QVGA_3fps);
			arducam_i2c_write_regs16(MT9D111_QVGA_15fps);
			//arducam_i2c_write_regs16(MT9D111_QVGA_30fps);
			arducam_delay_ms(1000);
			arducam_i2c_write16(0x97, 0x0020);
			arducam_i2c_write16(0xf0, 0x00);
			arducam_i2c_write16(0x21, 0x8403); //Mirror Column
			arducam_i2c_write16(0xC6, 0xA103);//SEQ_CMD
        	arducam_i2c_write16(0xC8, 0x0005); //SEQ_CMD
			break;
		}
#endif

#ifdef OV5642_CAM
		case smOV5642:
		{
			uint8_t reg_val;
			arducam_i2c_word_write(0x3008, 0x80);

			arducam_delay_ms(100);
			if(myCAM.m_fmt == fmtJPEG)
			{
				arducam_i2c_write_word_regs(OV5642_1080P_Video_setting);
				arducam_i2c_word_read(0x3818,&reg_val);
				arducam_i2c_word_write(0x3818, (reg_val | 0x20) & 0xBf);
				arducam_i2c_word_read(0x3621,&reg_val);
				arducam_i2c_word_write(0x3621, reg_val | 0x20);
			}
			else
			{
				arducam_i2c_write_word_regs(OV5642_RGB_QVGA);
				arducam_i2c_word_read(0x3818,&reg_val);
				arducam_i2c_word_write(0x3818, (reg_val | 0x60) & 0xff);
				arducam_i2c_word_read(0x3621,&reg_val);
				arducam_i2c_word_write(0x3621, reg_val & 0xdf);
			}
			break;
		}
#endif

#ifdef OV3640_CAM
		case smOV3640:
		{
			(void) arducam_i2c_write_word_regs(OV3640_QVGA);
			break;
		}
#endif

#ifdef OV2640_CAM
		case smOV2640:
		{
			arducam_i2c_write(0xff, 0x01);
			arducam_i2c_write(0x12, 0x80);
			arducam_delay_ms(100);
			if(myCAM.m_fmt == fmtJPEG)
			{
				arducam_i2c_write_regs(OV2640_JPEG_INIT);
				arducam_i2c_write_regs(OV2640_YUV422);
				arducam_i2c_write_regs(OV2640_JPEG);
				arducam_i2c_write(0xff, 0x01);
				arducam_i2c_write(0x15, 0x00);
				arducam_i2c_write_regs(OV2640_320x240_JPEG);
				//arducam_i2c_write(0xff, 0x00);
				//arducam_i2c_write(0x44, 0x32);
			}
			else
			{
				arducam_i2c_write_regs(OV2640_QVGA);
			}
			break;
		}
#endif

		case smOV9655:
		{

			break;
		}
		case smMT9M112:
		{

			break;
		}

		default:

			break;
	}
}

void arducam_flush_fifo(void)
{
	arducam_write_reg(ARDUCHIP_FIFO, FIFO_CLEAR_MASK);
}

void arducam_start_capture(void)
{
	arducam_write_reg(ARDUCHIP_FIFO, FIFO_START_MASK);
}

void arducam_clear_fifo_flag(void)
{
	arducam_write_reg(ARDUCHIP_FIFO, FIFO_CLEAR_MASK);
}

uint8_t arducam_read_fifo(void)
{
	uint8_t data;
	data = arducam_spi_read(0x3D);
	return data;
}

uint8_t arducam_read_reg(uint8_t addr)
{
	uint8_t data;
	data = arducam_spi_read(addr & 0x7F);
	return data;
}

void arducam_write_reg(uint8_t addr, uint8_t data)
{
	arducam_spi_write(addr | 0x80, data);
}

void arducam_set_jpeg_size(jpeg_size_t size)
{
#ifdef OV2640_CAM
	switch(size)
	{
		case sz160x120:
			arducam_i2c_write_regs(OV2640_160x120_JPEG);
			break;
		case sz176x144:
			arducam_i2c_write_regs(OV2640_176x144_JPEG);
			break;
		case sz320x240:
			arducam_i2c_write_regs(OV2640_320x240_JPEG);
			break;
		case sz352x288:
			arducam_i2c_write_regs(OV2640_352x288_JPEG);
			break;
		case sz640x480:
			arducam_i2c_write_regs(OV2640_640x480_JPEG);
			break;
		case sz800x600:
			arducam_i2c_write_regs(OV2640_800x600_JPEG);
			break;
		case sz1024x768:
			arducam_i2c_write_regs(OV2640_1024x768_JPEG);
			break;
		case sz1280x1024:
			arducam_i2c_write_regs(OV2640_1280x1024_JPEG);
			break;
		case sz1600x1200:
			arducam_i2c_write_regs(OV2640_1600x1200_JPEG);
			break;
		default:
			arducam_i2c_write_regs(OV2640_320x240_JPEG);
			break;
	}
#endif
}

void arducam_set_format(image_format_t fmt)
{
	myCAM.m_fmt = fmt;
}

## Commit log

2015-07-23 Working webcam prototype. Flash and connect to port 80.
2015-07-23 Updated i2c driver
2015-11-03 Removed the local i2c module
2015-11-03 Added FreeRTOS config for IRQ driven UART RX
2015-11-17 Added schematics and gerbers for the v1 board.
    [esparducam.brd, esparducam.sch]
2015-11-17 Verification plan for the v1 board.
2015-11-17 Changed reivsion label on schematic.
    [esparducam.sch]
2015-12-03 Version 2 of the Esparducam board
    [esparducam-v2.brd, esparducam-v2.sch]
2016-01-02 Esparducam board v2
    [esparducam-v2.GBL, esparducam-v2.GBO, esparducam-v2.GBP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]
2016-01-09 Added camera power cycle Removed the 1s delay at start
2016-01-21 Bugfix, a weird one...
    [camdriver.c]
2016-01-21 RFM69C addon board
    [ism-boardlet.brd, ism-boardlet.sch]
2016-01-21 Pogo pin addon board
    [esp-pinlet.brd, esp-pinlet.sch]
2016-01-21 ESP12 breakout board, untested
    [esp-boardlet.brd, esp-boardlet.sch]
2016-01-21 Added board image
2016-02-01 Added gerbers for pinlet. NOTE! Gerbers have not been produced but looks ok on circuitpeople.com
2016-11-13 Updated value for C6
    [esparducam-v2.brd, esparducam-v2.sch]
2017-09-20 Fixed code rot, compatible with latest EOR
    [arducam_arch_esp8266.c, camdriver.c, capture.c]
2017-10-03 Fixed server task stack size Added uHej for service discovery
    [capture.c]

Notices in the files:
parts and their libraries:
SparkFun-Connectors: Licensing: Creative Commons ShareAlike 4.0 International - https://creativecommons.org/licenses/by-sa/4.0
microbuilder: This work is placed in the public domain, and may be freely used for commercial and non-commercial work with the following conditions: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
